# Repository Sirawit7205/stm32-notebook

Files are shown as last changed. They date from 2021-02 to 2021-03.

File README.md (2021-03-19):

# STM32 Notebook

This is an STM32 dev board that is designed to be put on a B6 ring binder notebook as covers. The board size is 130x180mm and contains 21 4mm ring holes.

**Note: I did tried to follow best practices as much as possible while designing this board, but it is still intended to be used as a notebook cover. The devices fitted might not work to their fullest spec. Please exercise caution.**

## Features - Front

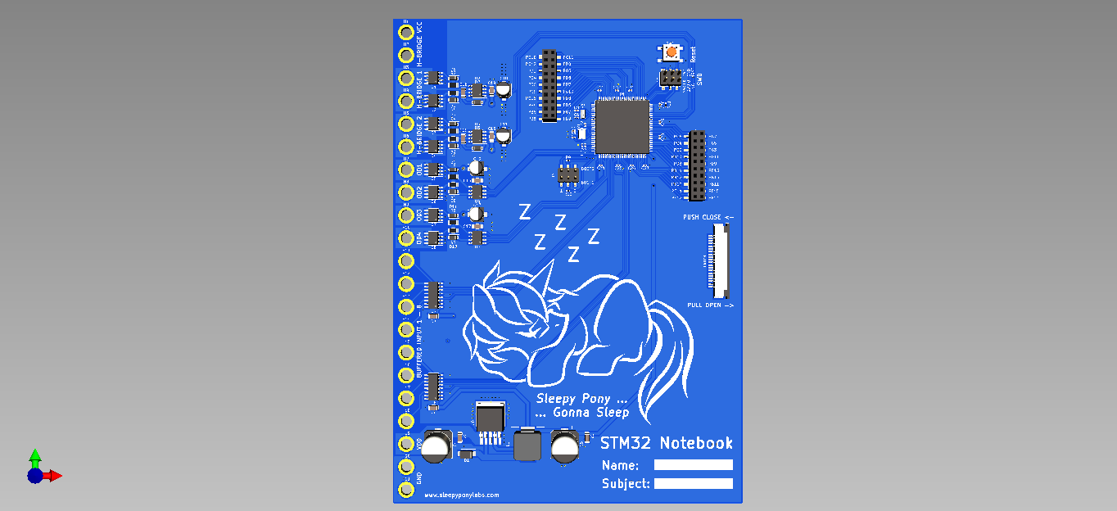
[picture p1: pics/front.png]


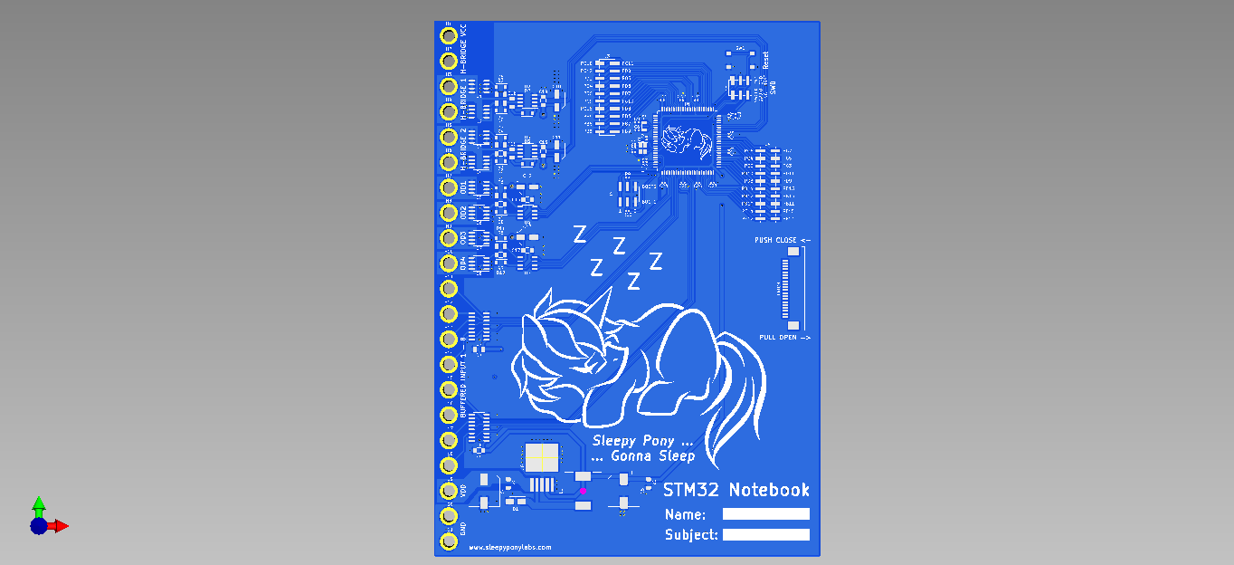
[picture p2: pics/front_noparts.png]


The front side is the devboard. Featuring:

 - An STM32F103ZCT6 ARM-Cortex M3 Microcontroller in a 144-pin LQFP package
 - External 16MHz crystal and 32.768kHz RTC crystal
 - 2x IRS2003 H-Bridge Drivers with a pair of IRF7403 MOSFET (total of 2 drivers)
 - 2x PM8834 MOSFET Drivers with two IRF7403 MOSFETs in an Open-Drain configuration (total of 4 drivers)
 - 2x CD4050 Buffer for translating higher voltage logic inputs into STM32's 3.3v logic (total of 8 inputs)
 - 40x IO pins breakout
 - BOOT0/BOOT1 headers
 - SWD headers
 - Reset button
 - LM2596S-3.3 Buck Converter
 - Cute ponies

## Features - Back

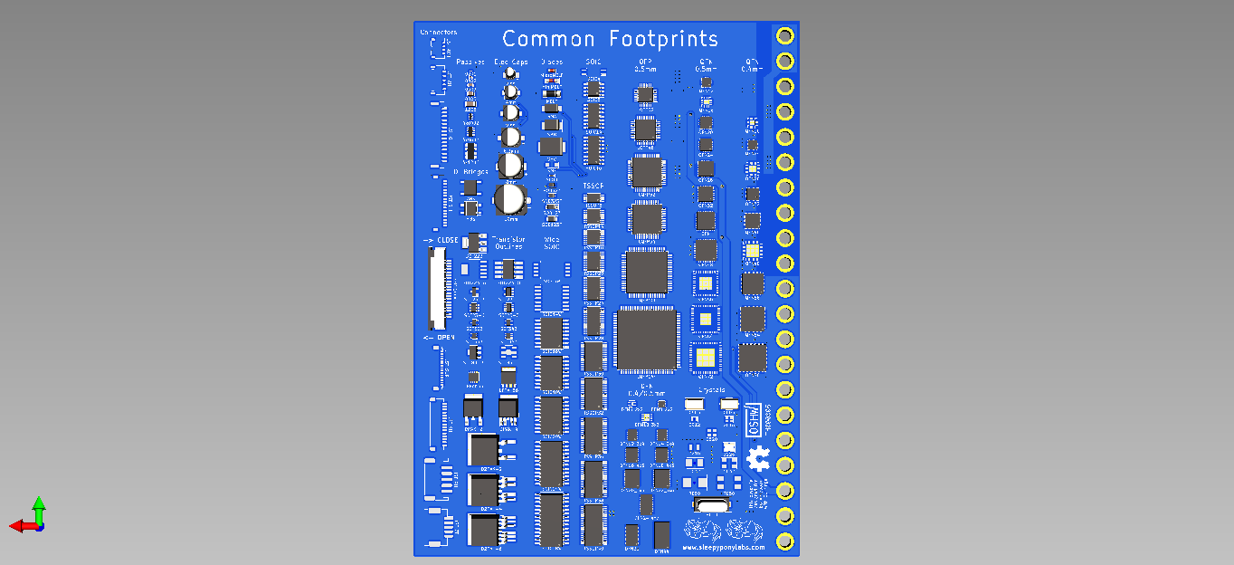
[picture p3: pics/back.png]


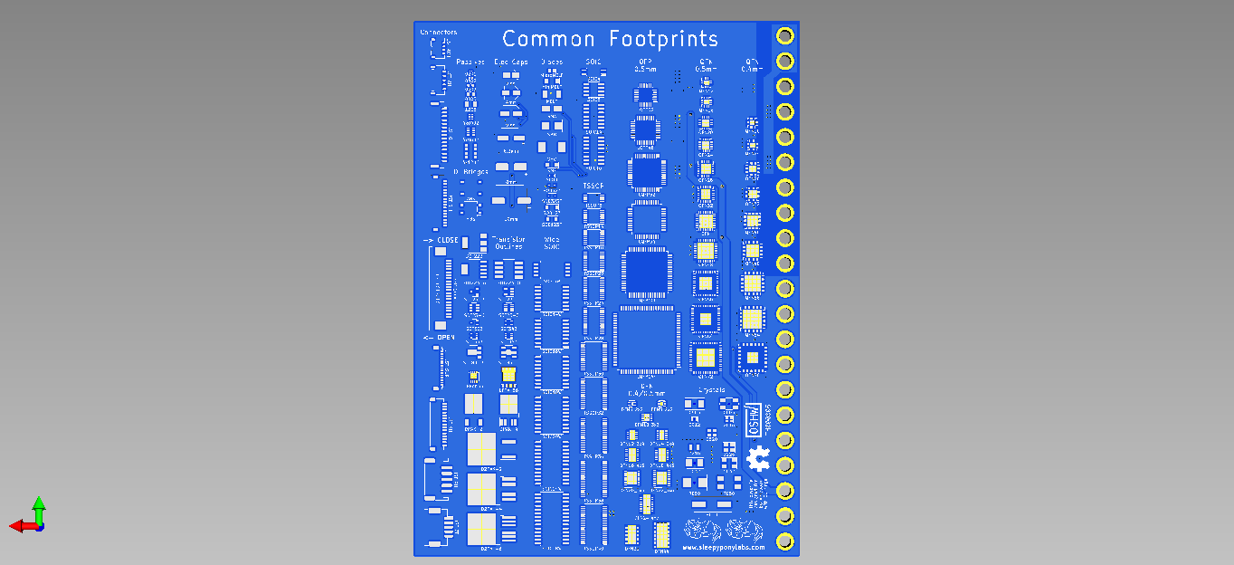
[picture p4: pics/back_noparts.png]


The back side is a PCB footprint reference guide. Featuring:

 - Passive components (0201 to 1206)
 - Electrolytic Capacitors (3mm to 10mm)
 - JST connectors (GH, SH, PH, ...)
 - Diodes (MELF, SMA, SMB, SOD123, SOD323, ...)
 - Diode Bridges (ABS, MBS)
 - Transistors (SOT23, SOT223, LFPAK56, DPAK, ...)
 - Crystals (HC49, 0603 to 7050, 2 and 4 pins versions)
 - SOICs (SOIC4, SOIC8, SOIC14, SOIC16)
 - Wide SOICs (SOIC8W to SOIC28W)
 - TSSOPs (TSSOP8 to TSSOP40)
 - QFPs 0.5mm pitch (LQFP32 to LQFP144)
 - DFNs 0.4mm and 0.5mm pitch (DFN6 to DFN44)
 - QFNs 0.4mm pitch (QFN20 to QFN76)
 - QFNs 0.5mm pitch (QFN12 to QFN72)
 - More cute ponies
 
 ## Features - Latch
 
 This board features a pair of 20-pin Slide-Lock FFP Connectors, one on each side. These connectors are there so you can add a 20-pin Same-Side FFC Cable to act as a notebook closing strap.
 
 ## Licenses
 
 Hardware is licensed under `SPDX-License-Identifier: Apache-2.0 WITH SHL-2.1`
 
 This project is a certified Open Source Hardware. OSHWA UID TH000006.
 https://certification.oshwa.org/th000006.html
 
 ## Credits

 - 3215 Crystal model by Sam Ma: https://grabcad.com/library/crystal-smd-3215-pin2-1
 - Inductor model by Gydius: https://grabcad.com/library/inductor-wurth-elektronik-74437324100-1

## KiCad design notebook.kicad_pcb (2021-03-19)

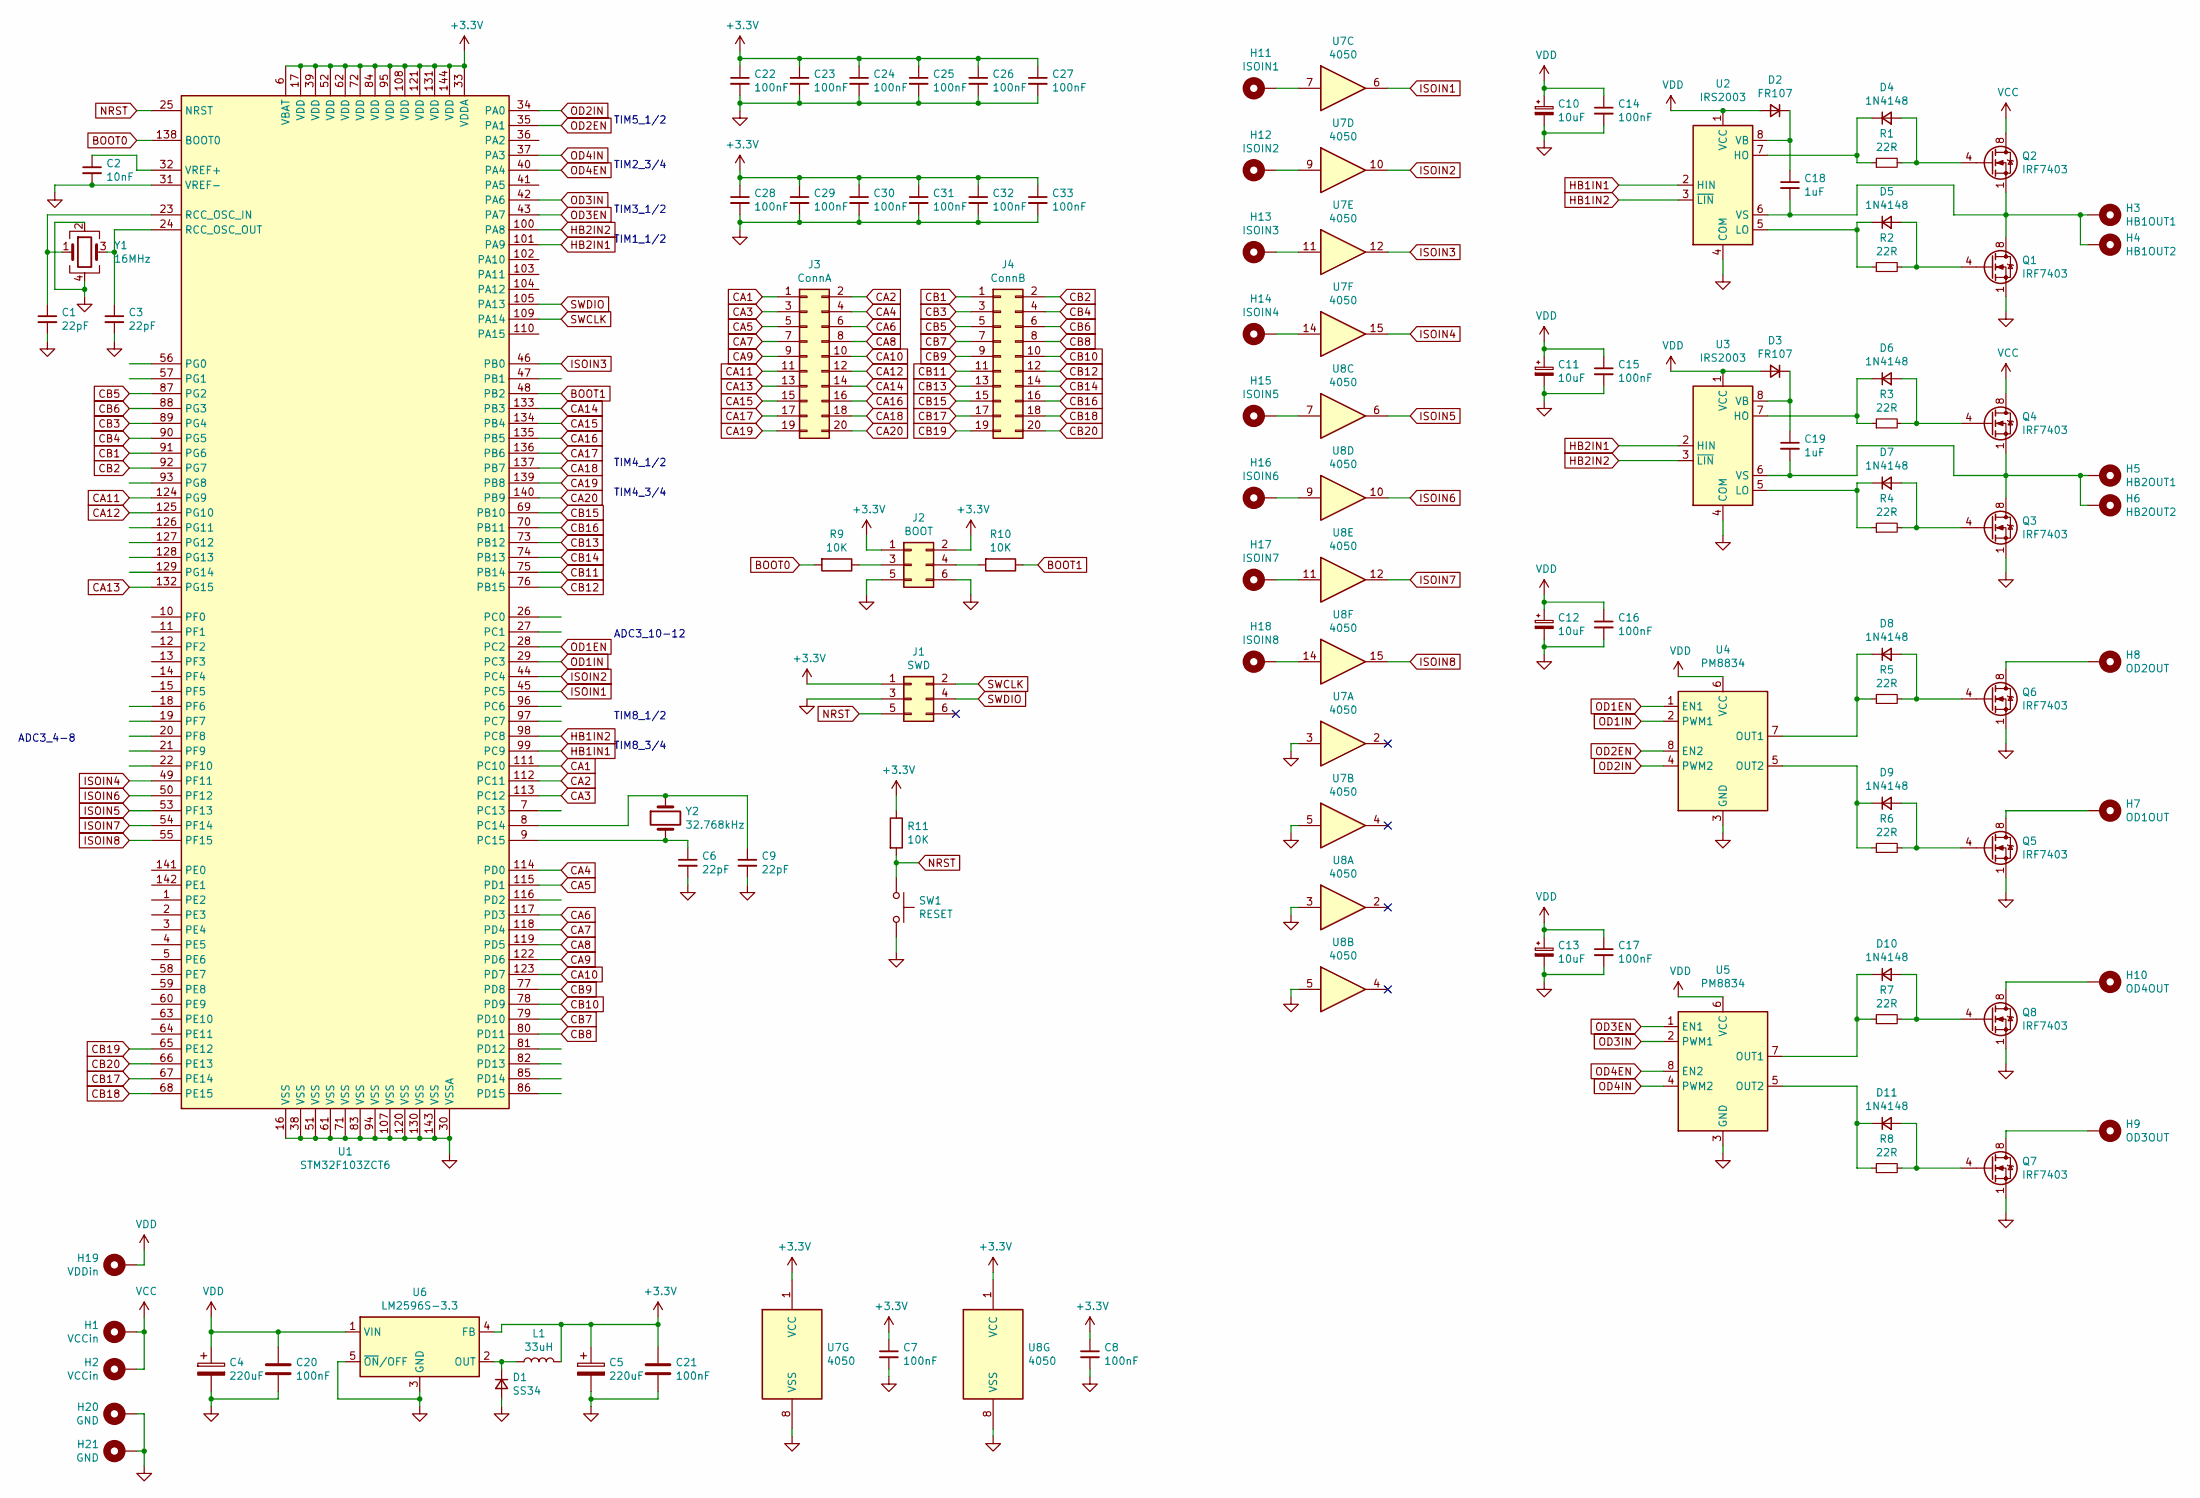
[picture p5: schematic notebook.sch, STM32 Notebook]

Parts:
C1, C3, C6, C9: 22pF; C_0402_1005Metric
C2: 10nF; C_0402_1005Metric
C4, C5: 220uF; CP_Elec_10x10
C7, C8, C14, C15, C16, C17, C20, C21: 100nF; C_1206_3216Metric
C10, C11, C12, C13: 10uF; CP_Elec_5x5.4
C18, C19: 1uF; C_1206_3216Metric
C22, C23, C24, C25, C26, C27, C28, C29, C30, C31, C32, C33: 100nF; C_0402_1005Metric
D1: SS34; D_SMA
D2, D3: FR107; D_SOD-123
D4, D5, D6, D7, D8, D9, D10, D11: 1N4148; D_SOD-123
H1, H2: VCCin; MountingHole_4mm_Pad_Thin
H3: HB1OUT1; MountingHole_4mm_Pad_Thin
H4: HB1OUT2; MountingHole_4mm_Pad_Thin
H5: HB2OUT1; MountingHole_4mm_Pad_Thin
H6: HB2OUT2; MountingHole_4mm_Pad_Thin
H7: OD1OUT; MountingHole_4mm_Pad_Thin
H8: OD2OUT; MountingHole_4mm_Pad_Thin
H9: OD3OUT; MountingHole_4mm_Pad_Thin
H10: OD4OUT; MountingHole_4mm_Pad_Thin
H11: ISOIN1; MountingHole_4mm_Pad_Thin
H12: ISOIN2; MountingHole_4mm_Pad_Thin
H13: ISOIN3; MountingHole_4mm_Pad_Thin
H14: ISOIN4; MountingHole_4mm_Pad_Thin
H15: ISOIN5; MountingHole_4mm_Pad_Thin
H16: ISOIN6; MountingHole_4mm_Pad_Thin
H17: ISOIN7; MountingHole_4mm_Pad_Thin
H18: ISOIN8; MountingHole_4mm_Pad_Thin
H19: VDDin; MountingHole_4mm_Pad_Thin
H20, H21: GND; MountingHole_4mm_Pad_Thin
J1: SWD; PinSocket_2x03_P2.54mm_Vertical_SMD
J2: BOOT; PinSocket_2x03_P2.54mm_Vertical_SMD
J3: ConnA; PinHeader_2x10_P2.54mm_Vertical_SMD
J4: ConnB; PinHeader_2x10_P2.54mm_Vertical_SMD
L1: 33uH; L_12x12mm_H8mm
Q1, Q2, Q3, Q4, Q5, Q6, Q7, Q8: IRF7403; SOIC-8_3.9x4.9mm_P1.27mm
R1, R2, R3, R4, R5, R6, R7, R8: 22R; R_1206_3216Metric
R9, R10, R11: 10K; R_0402_1005Metric
SW1: RESET; SW_SPST_PTS645
U1: STM32F103ZCT6; LQFP-144_20x20mm_P0.5mm
U2, U3: IRS2003; SOIC-8_3.9x4.9mm_P1.27mm
U4, U5: PM8834; SOIC-8_3.9x4.9mm_P1.27mm
U6: LM2596S-3.3; TO-263-5_TabPin3
U7, U8: 4050; SOIC-16_3.9x9.9mm_P1.27mm
Y1: 16MHz; Crystal_SMD_3225-4Pin_3.2x2.5mm
Y2: 32.768kHz; Crystal_SMD_3215-2Pin_3.2x1.5mm

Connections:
+3V3: C5.1, C7.1, C8.1, C21.1, C22.1, C23.1, C24.1, C25.1, C26.1, C27.1, C28.1, C29.1, C30.1, C31.1, C32.1, C33.1, J1.1, J2.1, J2.2, L1.2, R11.1, U1.6 (VBAT), U1.17 (VDD), U1.33 (VDDA), U1.39 (VDD), U1.52 (VDD), U1.62 (VDD), U1.72 (VDD), U1.84 (VDD), U1.95 (VDD), U1.108 (VDD), U1.121 (VDD), U1.131 (VDD), U1.144 (VDD), U6.4 (FB), U7.1 (VCC), U8.1 (VCC)
BOOT0: R9.2, U1.138 (BOOT0)
BOOT1: R10.1, U1.48 (PB2)
CA1: J3.1, U1.111 (PC10)
CA2: J3.2, U1.112 (PC11)
CA3: J3.3, U1.113 (PC12)
CA4: J3.4, U1.114 (PD0)
CA5: J3.5, U1.115 (PD1)
CA6: J3.6, U1.117 (PD3)
CA7: J3.7, U1.118 (PD4)
CA8: J3.8, U1.119 (PD5)
CA9: J3.9, U1.122 (PD6)
CA10: J3.10, U1.123 (PD7)
CA11: J3.11, U1.124 (PG9)
CA12: J3.12, U1.125 (PG10)
CA13: J3.13, U1.132 (PG15)
CA14: J3.14, U1.133 (PB3)
CA15: J3.15, U1.134 (PB4)
CA16: J3.16, U1.135 (PB5)
CA17: J3.17, U1.136 (PB6)
CA18: J3.18, U1.137 (PB7)
CA19: J3.19, U1.139 (PB8)
CA20: J3.20, U1.140 (PB9)
CB1: J4.1, U1.91 (PG6)
CB2: J4.2, U1.92 (PG7)
CB3: J4.3, U1.89 (PG4)
CB4: J4.4, U1.90 (PG5)
CB5: J4.5, U1.87 (PG2)
CB6: J4.6, U1.88 (PG3)
CB7: J4.7, U1.79 (PD10)
CB8: J4.8, U1.80 (PD11)
CB9: J4.9, U1.77 (PD8)
CB10: J4.10, U1.78 (PD9)
CB11: J4.11, U1.75 (PB14)
CB12: J4.12, U1.76 (PB15)
CB13: J4.13, U1.73 (PB12)
CB14: J4.14, U1.74 (PB13)
CB15: J4.15, U1.69 (PB10)
CB16: J4.16, U1.70 (PB11)
CB17: J4.17, U1.67 (PE14)
CB18: J4.18, U1.68 (PE15)
CB19: J4.19, U1.65 (PE12)
CB20: J4.20, U1.66 (PE13)
GND: C1.2, C2.2, C3.2, C4.2, C5.2, C6.2, C7.2, C8.2, C9.2, C10.2, C11.2, C12.2, C13.2, C14.2, C15.2, C16.2, C17.2, C20.2, C21.2, C22.2, C23.2, C24.2, C25.2, C26.2, C27.2, C28.2, C29.2, C30.2, C31.2, C32.2, C33.2, D1.2 (A), H20.1, H21.1, J1.3, J2.5, J2.6, Q1.1 (S), Q1.2 (S), Q1.3 (S), Q3.1 (S), Q3.2 (S), Q3.3 (S), Q5.1 (S), Q5.2 (S), Q5.3 (S), Q6.1 (S), Q6.2 (S), Q6.3 (S), Q7.1 (S), Q7.2 (S), Q7.3 (S), Q8.1 (S), Q8.2 (S), Q8.3 (S), SW1.2, U1.16 (VSS), U1.30 (VSSA), U1.31 (VREF-), U1.38 (VSS), U1.51 (VSS), U1.61 (VSS), U1.71 (VSS), U1.83 (VSS), U1.94 (VSS), U1.107 (VSS), U1.120 (VSS), U1.130 (VSS), U1.143 (VSS), U2.4 (COM), U3.4 (COM), U4.3 (GND), U5.3 (GND), U6.3 (GND), U6.5 (~ON~/OFF), U7.3, U7.5, U7.8 (VSS), U8.3, U8.5, U8.8 (VSS), Y1.2, Y1.4
HB1IN1: U1.99 (PC9), U2.2 (HIN)
HB1IN2: U1.98 (PC8), U2.3 (~LIN)
HB2IN1: U1.101 (PA9), U3.2 (HIN)
HB2IN2: U1.100 (PA8), U3.3 (~LIN)
ISOIN1: U1.45 (PC5), U7.6
ISOIN2: U1.44 (PC4), U7.10
ISOIN3: U1.46 (PB0), U7.12
ISOIN4: U1.49 (PF11), U7.15
ISOIN5: U1.53 (PF13), U8.6
ISOIN6: U1.50 (PF12), U8.10
ISOIN7: U1.54 (PF14), U8.12
ISOIN8: U1.55 (PF15), U8.15
NRST: J1.5, R11.2, SW1.1, U1.25 (NRST)
unnamed: C1.1, U1.23 (RCC_OSC_IN), Y1.1
unnamed: C2.1, U1.32 (VREF+)
unnamed: C3.1, U1.24 (RCC_OSC_OUT), Y1.3
unnamed: C6.1, U1.9 (PC15), Y2.2
unnamed: C9.1, U1.8 (PC14), Y2.1
unnamed: C18.1, D2.1 (K), U2.8 (VB)
unnamed: C18.2, H3.1, H4.1, Q1.5 (D), Q1.6 (D), Q1.7 (D), Q1.8 (D), Q2.1 (S), Q2.2 (S), Q2.3 (S), U2.6 (VS)
unnamed: C19.1, D3.1 (K), U3.8 (VB)
unnamed: C19.2, H5.1, H6.1, Q3.5 (D), Q3.6 (D), Q3.7 (D), Q3.8 (D), Q4.1 (S), Q4.2 (S), Q4.3 (S), U3.6 (VS)
unnamed: D1.1 (K), L1.1, U6.2 (OUT)
unnamed: D4.1 (K), R1.1, U2.7 (HO)
unnamed: D4.2 (A), Q2.4 (G), R1.2
unnamed: D5.1 (K), R2.1, U2.5 (LO)
unnamed: D5.2 (A), Q1.4 (G), R2.2
unnamed: D6.1 (K), R3.1, U3.7 (HO)
unnamed: D6.2 (A), Q4.4 (G), R3.2
unnamed: D7.1 (K), R4.1, U3.5 (LO)
unnamed: D7.2 (A), Q3.4 (G), R4.2
unnamed: D8.1 (K), R5.1, U4.7 (OUT1)
unnamed: D8.2 (A), Q6.4 (G), R5.2
unnamed: D9.1 (K), R6.1, U4.5 (OUT2)
unnamed: D9.2 (A), Q5.4 (G), R6.2
unnamed: D10.1 (K), R7.1, U5.7 (OUT1)
unnamed: D10.2 (A), Q8.4 (G), R7.2
unnamed: D11.1 (K), R8.1, U5.5 (OUT2)
unnamed: D11.2 (A), Q7.4 (G), R8.2
unnamed: H7.1, Q5.5 (D), Q5.6 (D), Q5.7 (D), Q5.8 (D)
unnamed: H8.1, Q6.5 (D), Q6.6 (D), Q6.7 (D), Q6.8 (D)
unnamed: H9.1, Q7.5 (D), Q7.6 (D), Q7.7 (D), Q7.8 (D)
unnamed: H10.1, Q8.5 (D), Q8.6 (D), Q8.7 (D), Q8.8 (D)
unnamed: H11.1, U7.7
unnamed: H12.1, U7.9
unnamed: H13.1, U7.11
unnamed: H14.1, U7.14
unnamed: H15.1, U8.7
unnamed: H16.1, U8.9
unnamed: H17.1, U8.11
unnamed: H18.1, U8.14
unnamed: J2.3, R9.1
unnamed: J2.4, R10.2
OD1EN: U1.28 (PC2), U4.1 (EN1)
OD1IN: U1.29 (PC3), U4.2 (PWM1)
OD2EN: U1.35 (PA1), U4.8 (EN2)
OD2IN: U1.34 (PA0), U4.4 (PWM2)
OD3EN: U1.43 (PA7), U5.1 (EN1)
OD3IN: U1.42 (PA6), U5.2 (PWM1)
OD4EN: U1.40 (PA4), U5.8 (EN2)
OD4IN: U1.37 (PA3), U5.4 (PWM2)
SWCLK: J1.2, U1.109 (PA14)
SWDIO: J1.4, U1.105 (PA13)
VCC: H1.1, H2.1, Q2.5 (D), Q2.6 (D), Q2.7 (D), Q2.8 (D), Q4.5 (D), Q4.6 (D), Q4.7 (D), Q4.8 (D)
VDD: C4.1, C10.1, C11.1, C12.1, C13.1, C14.1, C15.1, C16.1, C17.1, C20.1, D2.2 (A), D3.2 (A), H19.1, U2.1 (VCC), U3.1 (VCC), U4.6 (VCC), U5.6 (VCC), U6.1 (VIN)

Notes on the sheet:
TIM5_1/2
TIM3_1/2
TIM8_1/2
TIM1_1/2
TIM4_1/2
TIM2_3/4
TIM4_3/4
TIM8_3/4
ADC3_4-8
ADC3_10-12

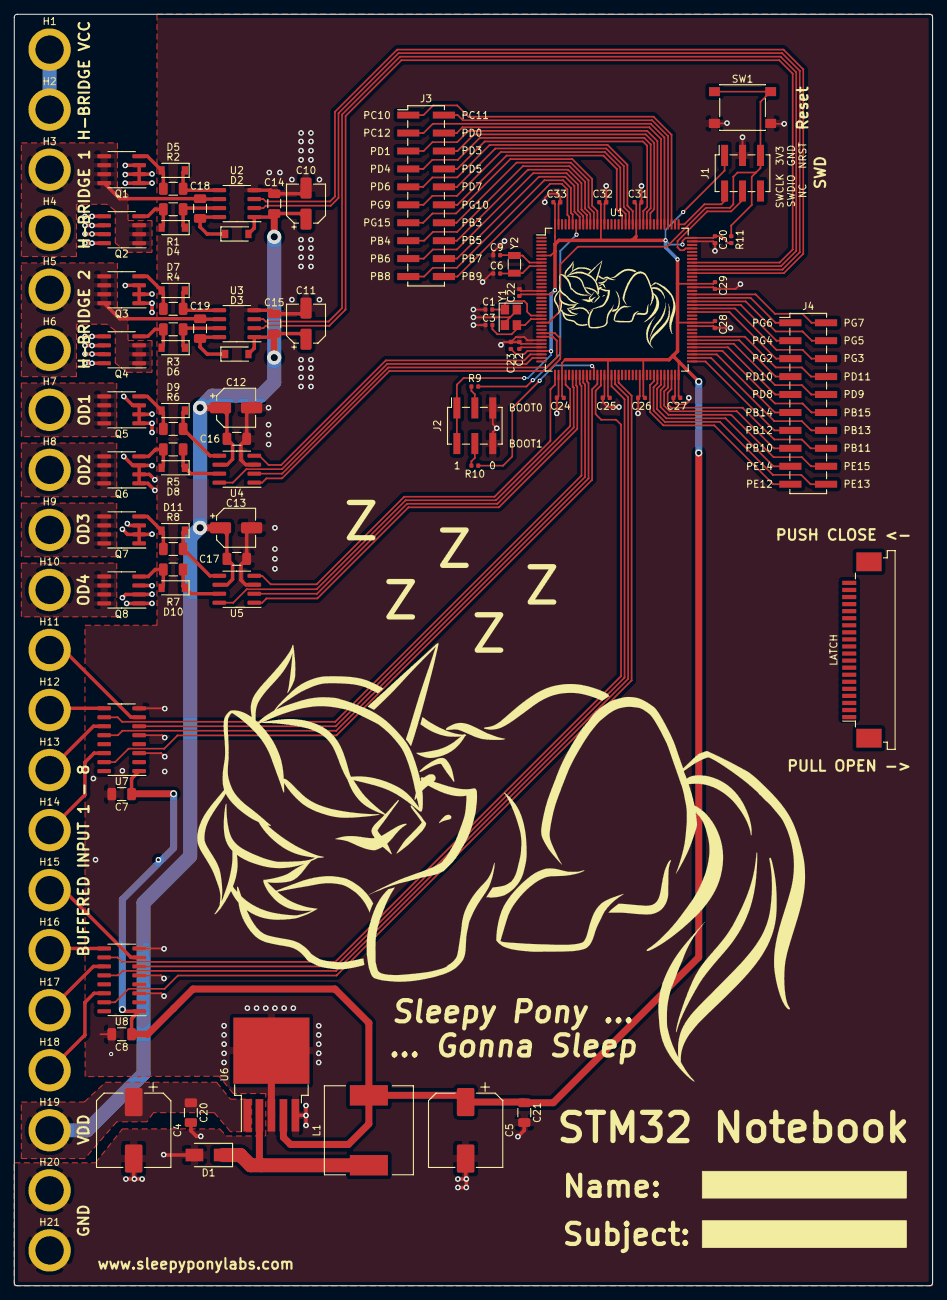
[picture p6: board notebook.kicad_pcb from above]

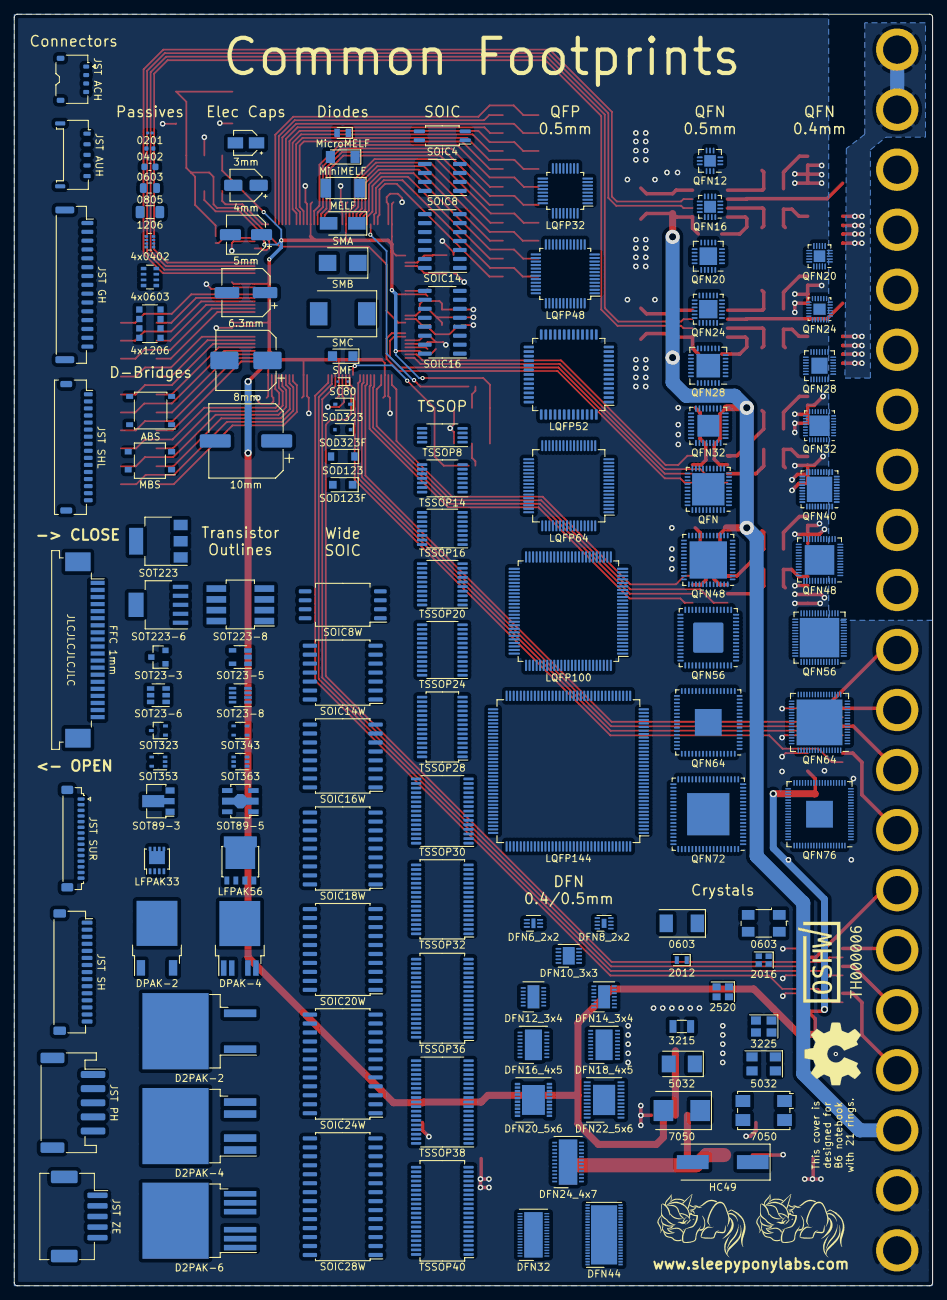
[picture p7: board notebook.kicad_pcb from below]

Board: 2 copper layers, 130.0 x 180.0 mm, 231 parts (130 on the bottom side), 109 nets.

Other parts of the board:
3mm: CP_Elec_3x5.3
4mm: CP_Elec_4x3
4x0402: R_Array_Convex_4x0402
4x0603: R_Array_Convex_4x0603
4x1206: R_Array_Convex_4x1206
5mm: CP_Elec_5x3
6.3mm: CP_Elec_6.3x3
8mm: CP_Elec_8x5.4
10mm: CP_Elec_10x7.7
0201: C_0201_0603Metric
0402: C_0402_1005Metric
0603: Crystal_SMD_0603-4Pin_6.0x3.5mm
0603#2: Crystal_SMD_0603-2Pin_6.0x3.5mm
0603#3: C_0603_1608Metric
0805: C_0805_2012Metric
1206: C_1206_3216Metric
2012: Crystal_SMD_2012-2Pin_2.0x1.2mm
2016: Crystal_SMD_2016-4Pin_2.0x1.6mm
2520: Crystal_SMD_2520-4Pin_2.5x2.0mm
3215: Crystal_SMD_3215-2Pin_3.2x1.5mm
3225: Crystal_SMD_3225-4Pin_3.2x2.5mm
5032: Crystal_SMD_5032-4Pin_5.0x3.2mm
5032#2: Crystal_SMD_5032-2Pin_5.0x3.2mm
7050: Crystal_SMD_7050-4Pin_7.0x5.0mm
7050#2: Crystal_SMD_7050-2Pin_7.0x5.0mm
ABS: Diode_Bridge_Diotec_ABS
D2PAK-2: TO-263-2
D2PAK-4: TO-263-4
D2PAK-6: TO-263-6
DFN6_2x2: DFN-6-1EP_2x2mm_P0.5mm_EP0.6x1.37mm
DFN8_2x2: DFN-8-1EP_2x2mm_P0.5mm_EP0.7x1.3mm
DFN10_3x3: DFN-10-1EP_3x3mm_P0.5mm_EP1.7x2.5mm
DFN12_3x4: DFN-12-1EP_3x4mm_P0.5mm_EP1.7x3.3mm
DFN14_3x4: DFN-14-1EP_3x4mm_P0.5mm_EP1.7x3.3mm
DFN16_4x5: DFN-16-1EP_4x5mm_P0.5mm_EP2.44x4.34mm
DFN18_4x5: DFN-18-1EP_4x5mm_P0.5mm_EP2.44x4.34mm
DFN20_5x6: DFN-20-1EP_5x6mm_P0.5mm_EP3.24x4.24mm
DFN22_5x6: DFN-22-1EP_5x6mm_P0.5mm_EP3.14x4.3mm
DFN24_4x7: DFN-24-1EP_4x7mm_P0.5mm_EP2.64x6.44mm
DFN32: DFN-32-1EP_4x7mm_P0.4mm_EP2.64x6.44mm
DFN44: DFN-44-1EP_5x8.9mm_P0.4mm_EP3.7x8.4mm
DPAK-2: TO-252-2
DPAK-4: TO-252-4
FFC 1mm: TE_2-84952-0_1x20-1MP_P1.0mm_Horizontal
HC49: Crystal_SMD_HC49-SD
JST ACH: JST_ACH_BM04B-ACHSS-A-GAN-ETF_1x04-1MP_P1.20mm_Ve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; JST_ACH_BM04B-ACHSS-A-GAN-ETF_1x04-1MP_P1.20mm_Vertical
JST AUH: JST_AUH_BM05B-AUHKS-GA-TB_1x05-1MP_P1.50mm_Vertic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; JST_AUH_BM05B-AUHKS-GA-TB_1x05-1MP_P1.50mm_Vertical
JST GH: JST_GH_SM15B-GHS-TB_1x15-1MP_P1.25mm_Horizontal
JST PH: JST_PH_S5B-PH-SM4-TB_1x05-1MP_P2.00mm_Horizontal
JST SH: JST_SH_SM15B-SRSS-TB_1x15-1MP_P1.00mm_Horizontal
JST SHL: JST_SHL_SM16B-SHLS-TF_1x16-1MP_P1.00mm_Horizontal
JST SUR: JST_SUR_SM15B-SURS-TF_1x15-1MP_P0.80mm_Horizontal
JST ZE: JST_ZE_SM05B-ZESS-TB_1x05-1MP_P1.50mm_Horizontal
LATCH: TE_2-84952-0_1x20-1MP_P1.0mm_Horizontal
LFPAK33: LFPAK33
LFPAK56: LFPAK56
LQFP32: LQFP-32_5x5mm_P0.5mm
LQFP48: LQFP-48_7x7mm_P0.5mm
LQFP52: LQFP-52_10x10mm_P0.65mm
LQFP64: LQFP-64_10x10mm_P0.5mm
LQFP100: LQFP-100_14x14mm_P0.5mm
LQFP144: LQFP-144_20x20mm_P0.5mm
MBS: TO-269AA
MELF: D_MELF
MicroMELF: D_MicroMELF
MiniMELF: D_MiniMELF
QFN: QFN-40-1EP_6x6mm_P0.5mm_EP4.6x4.6mm
QFN12: QFN-12-1EP_3x3mm_P0.5mm_EP1.65x1.65mm
QFN16: QFN-16-1EP_3x3mm_P0.5mm_EP1.7x1.7mm
QFN20: QFN-20-1EP_4x4mm_P0.5mm_EP2.5x2.5mm
QFN20#2: QFN-20-1EP_3x3mm_P0.4mm_EP1.65x1.65mm
QFN24: QFN-24-1EP_4x4mm_P0.5mm_EP2.6x2.6mm
QFN24#2: QFN-24-1EP_3x3mm_P0.4mm_EP1.75x1.6mm
QFN28: QFN-28-1EP_4x4mm_P0.4mm_EP2.3x2.3mm
QFN28#2: QFN-28-1EP_5x5mm_P0.5mm_EP3.35x3.35mm
QFN32: QFN-32-1EP_4x4mm_P0.4mm_EP2.9x2.9mm
QFN32#2: QFN-32-1EP_5x5mm_P0.5mm_EP3.1x3.1mm
QFN40: QFN-40-1EP_5x5mm_P0.4mm_EP3.6x3.6mm
QFN48: QFN-48-1EP_6x6mm_P0.4mm_EP4.2x4.2mm
QFN48#2: QFN-48-1EP_7x7mm_P0.5mm_EP5.3x5.3mm
QFN56: QFN-56-1EP_8x8mm_P0.5mm_EP4.3x4.3mm
QFN56#2: QFN-56-1EP_7x7mm_P0.4mm_EP5.6x5.6mm
QFN64: QFN-64-1EP_8x8mm_P0.4mm_EP6.5x6.5mm
QFN64#2: QFN-64-1EP_9x9mm_P0.5mm_EP3.8x3.8mm
QFN72: QFN-72-1EP_10x10mm_P0.5mm_EP6x6mm
QFN76: QFN-76-1EP_9x9mm_P0.4mm_EP3.8x3.8mm
Ref**: Val**; TH000006_svg2sz
SC80: D_SC-80
SMA: D_SMA
SMB: D_SMB
SMC: D_SMC
SMF: D_SMF
SOD123: D_SOD-123
SOD123F: D_SOD-123F
SOD323: D_SOD-323
SOD323F: D_SOD-323F
SOIC4: SOIC-4_4.55x2.6mm_P1.27mm
SOIC8: SOIC-8_3.9x4.9mm_P1.27mm
SOIC8W: SOIC-8_7.5x5.85mm_P1.27mm
SOIC14: SOIC-14_3.9x8.7mm_P1.27mm
SOIC14W: SOIC-14W_7.5x9mm_P1.27mm
SOIC16: SOIC-16_3.9x9.9mm_P1.27mm
SOIC16W: SOIC-16W_7.5x10.3mm_P1.27mm
SOIC18W: SOIC-18W_7.5x11.6mm_P1.27mm
SOIC20W: SOIC-20W_7.5x12.8mm_P1.27mm
SOIC24W: SOIC-24W_7.5x15.4mm_P1.27mm
SOIC28W: SOIC-28W_7.5x17.9mm_P1.27mm
SOT23-3: SOT-23
SOT23-5: SOT-23-5
SOT23-6: SOT-23-6
SOT23-8: SOT-23-8
SOT89-3: SOT-89-3
SOT89-5: SOT-89-5
SOT223: SOT-223
SOT223-6: SOT-223-6
SOT223-8: SOT-223-8
SOT323: SOT-323_SC-70
SOT343: SOT-343_SC-70-4
SOT353: SOT-353_SC-70-5
SOT363: SOT-363_SC-70-6
TSSOP8: TSSOP-8_4.4x3mm_P0.65mm
TSSOP14: TSSOP-14_4.4x5mm_P0.65mm
TSSOP16: TSSOP-16_4.4x5mm_P0.65mm
TSSOP20: TSSOP-20_4.4x6.5mm_P0.65mm
TSSOP24: TSSOP-24_4.4x7.8mm_P0.65mm
TSSOP28: TSSOP-28_4.4x9.7mm_P0.65mm
TSSOP30: TSSOP-30_6.1x9.7mm_P0.65mm
TSSOP32: TSSOP-32_6.1x11mm_P0.65mm
TSSOP36: TSSOP-36_6.1x12.5mm_P0.65mm
TSSOP38: TSSOP-38_6.1x12.5mm_P0.65mm
TSSOP40: TSSOP-40_6.1x14mm_P0.65mm
